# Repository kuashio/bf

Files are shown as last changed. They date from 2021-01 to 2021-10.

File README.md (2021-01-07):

# Brainfuino [-]+.
An Arduino competitor that runs native brainfuck! I've condensed the explanation in this video: https://youtu.be/QloNq8AoHvU

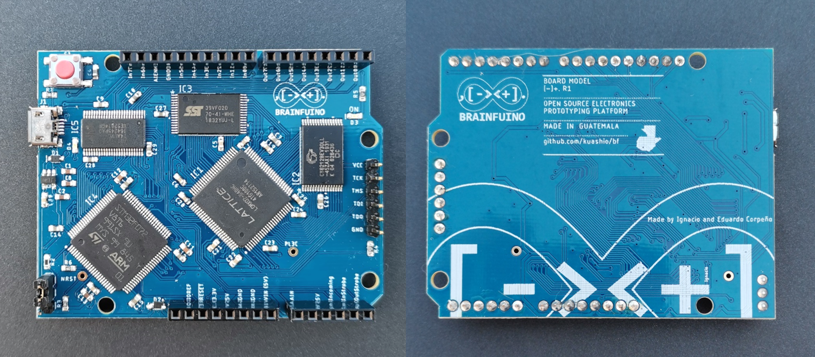
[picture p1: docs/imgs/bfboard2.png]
The Brainfuino [-]+.
[](https://youtu.be/QloNq8AoHvU)

Before going further, please make sure you know (or remember) what brainfuck is. [Here's Wikipedia's entry as a refresher](https://en.wikipedia.org/wiki/Brainfuck).

Also, before moving forward: This is not a joke. It ***is*** about a joke programming language, but a joke lots of nerds are very fond of. When I say nerds, I mean real geeks: Not gamers or technophiles, but geeks who like to read [The Art of Computer Programming](https://en.wikipedia.org/wiki/The_Art_of_Computer_Programming) just for kicks!

The Brainfuino [-]+. (pronounced "Brainfuino Uno") is a development board for a brainfuck soft processor I wrote in Verilog, named [***brainfuck_uP***](https://github.com/kuashio/brainfuck_uP) (as in "brainfuck microprocessor"), which runs brainfuck code natively, that is, the plain text of a brainfuck source file, yes, ascii characters.

Here are some details:

- brainfuck_uP is implemented in a Lattice MachXO2 FPGA, very much like the one in the [TinyFPGA AX2](https://www.sparkfun.com/products/14828) board, but in a TQFP100 package.
- brainfuck_uP is a *Harvard* machine, so it has two separate buses for its program and data memories. 
- The Brainfuino has a 128kB RAM chip and a 256kB chip, both with a good old parallel interface to work as the data and program memories of brainfuck_uP respectively.
- The I/O is adapted from 3.3V logic to TTL with a separate chip (to resemble the Arduino Uno).
- The host computer interface is a USB Virtual COM port implemented with an STM32F072 MCU, which overrides the input/output ports of brainfuck_uP for easy user-brainfuck interaction.
- The MCU is also donating its ADC to give Brainfuino the power of analog input. 
- The board has hardware for updating both the MCU firmware and the FPGA design.

## Advantages over the Arduino Uno

This product is intended as anything around brainfuck and esoteric programming languages: A joke. An elaborate joke. A geek toy.

So, if we take the Arduino as a competitor, here are some advantages:

- Brainfuino runs brainfuck! You'll get to learn a classic esoteric programming language.
- Brainfuino is the only brainfuck MCU platform of its kind (that I know of).
- Brainfuino is capable of at least competing with the Arduino by having an analog input channel.
- Brainfuino may serve as a teaching tool for several things: FPGA soft-processor development, computer science, esoteric programming languages, tinkering, hardware, etc.
- Lots of fun by matching the Arduino Community's codebase.
- Bragging rights for writing code that works! You certainly won't get that from the Arduino. 
- A *Guinness Record* may come out from the Brainfuino Community. Think an Operating System, or an actual home security system!

## Computer Languages

There are three computer languages involved. Only the first one is really intended for the end-user:

- **brainfuck:** Users will write their code in brainfuck, and the Brainfuino will run it.
- **Verilog:** brainfuck_uP was written in Verilog. The final .jedec file may be written into the FPGA's internal ROM at any time.
- **C/C++:** The firmware in the STM32 MCU was written in C. This firmware can be written into the MCU at any time as well.

## Related Projects

- [brainfuck_uP](https://github.com/kuashio/brainfuck_up). The soft processor running on the Brainfuino.
- [Brainfuino MCU firmware](https://github.com/kuashio/brainfuino-firmware). The firmware running in the STM32F072 MCU.

- [Visual brainfuck](https://sites.google.com/site/visualbf/). A brainfuck IDE I finished back in 2011.

## Contact

Eduardo Corpeño

For bug report or anything related to Brainfuino, I may be reached at kuashio@gmail.com

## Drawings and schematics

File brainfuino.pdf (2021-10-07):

J1

# BRD_RST BRD_RST

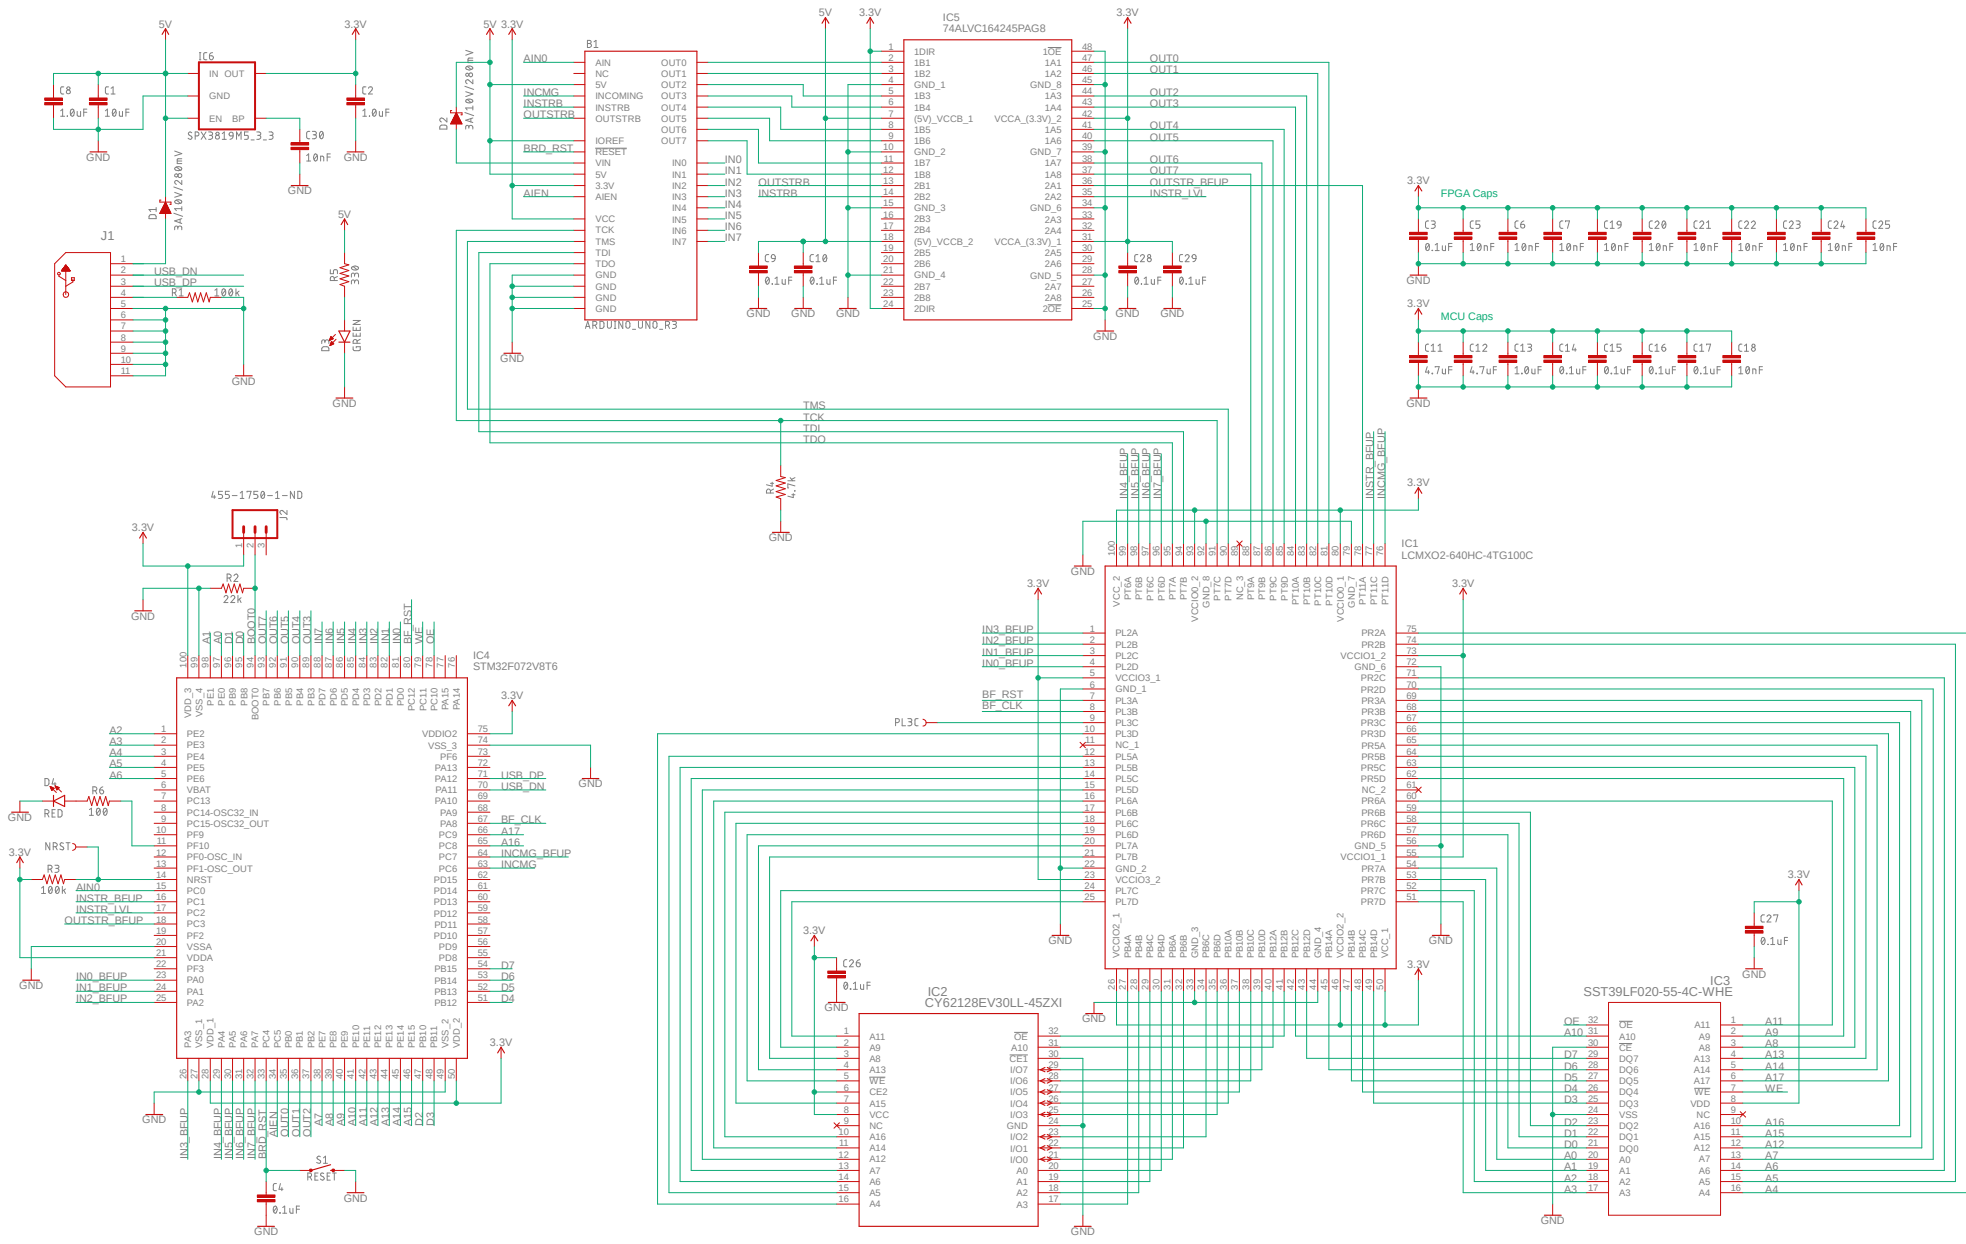
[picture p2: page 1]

TCK
TDI
TDO

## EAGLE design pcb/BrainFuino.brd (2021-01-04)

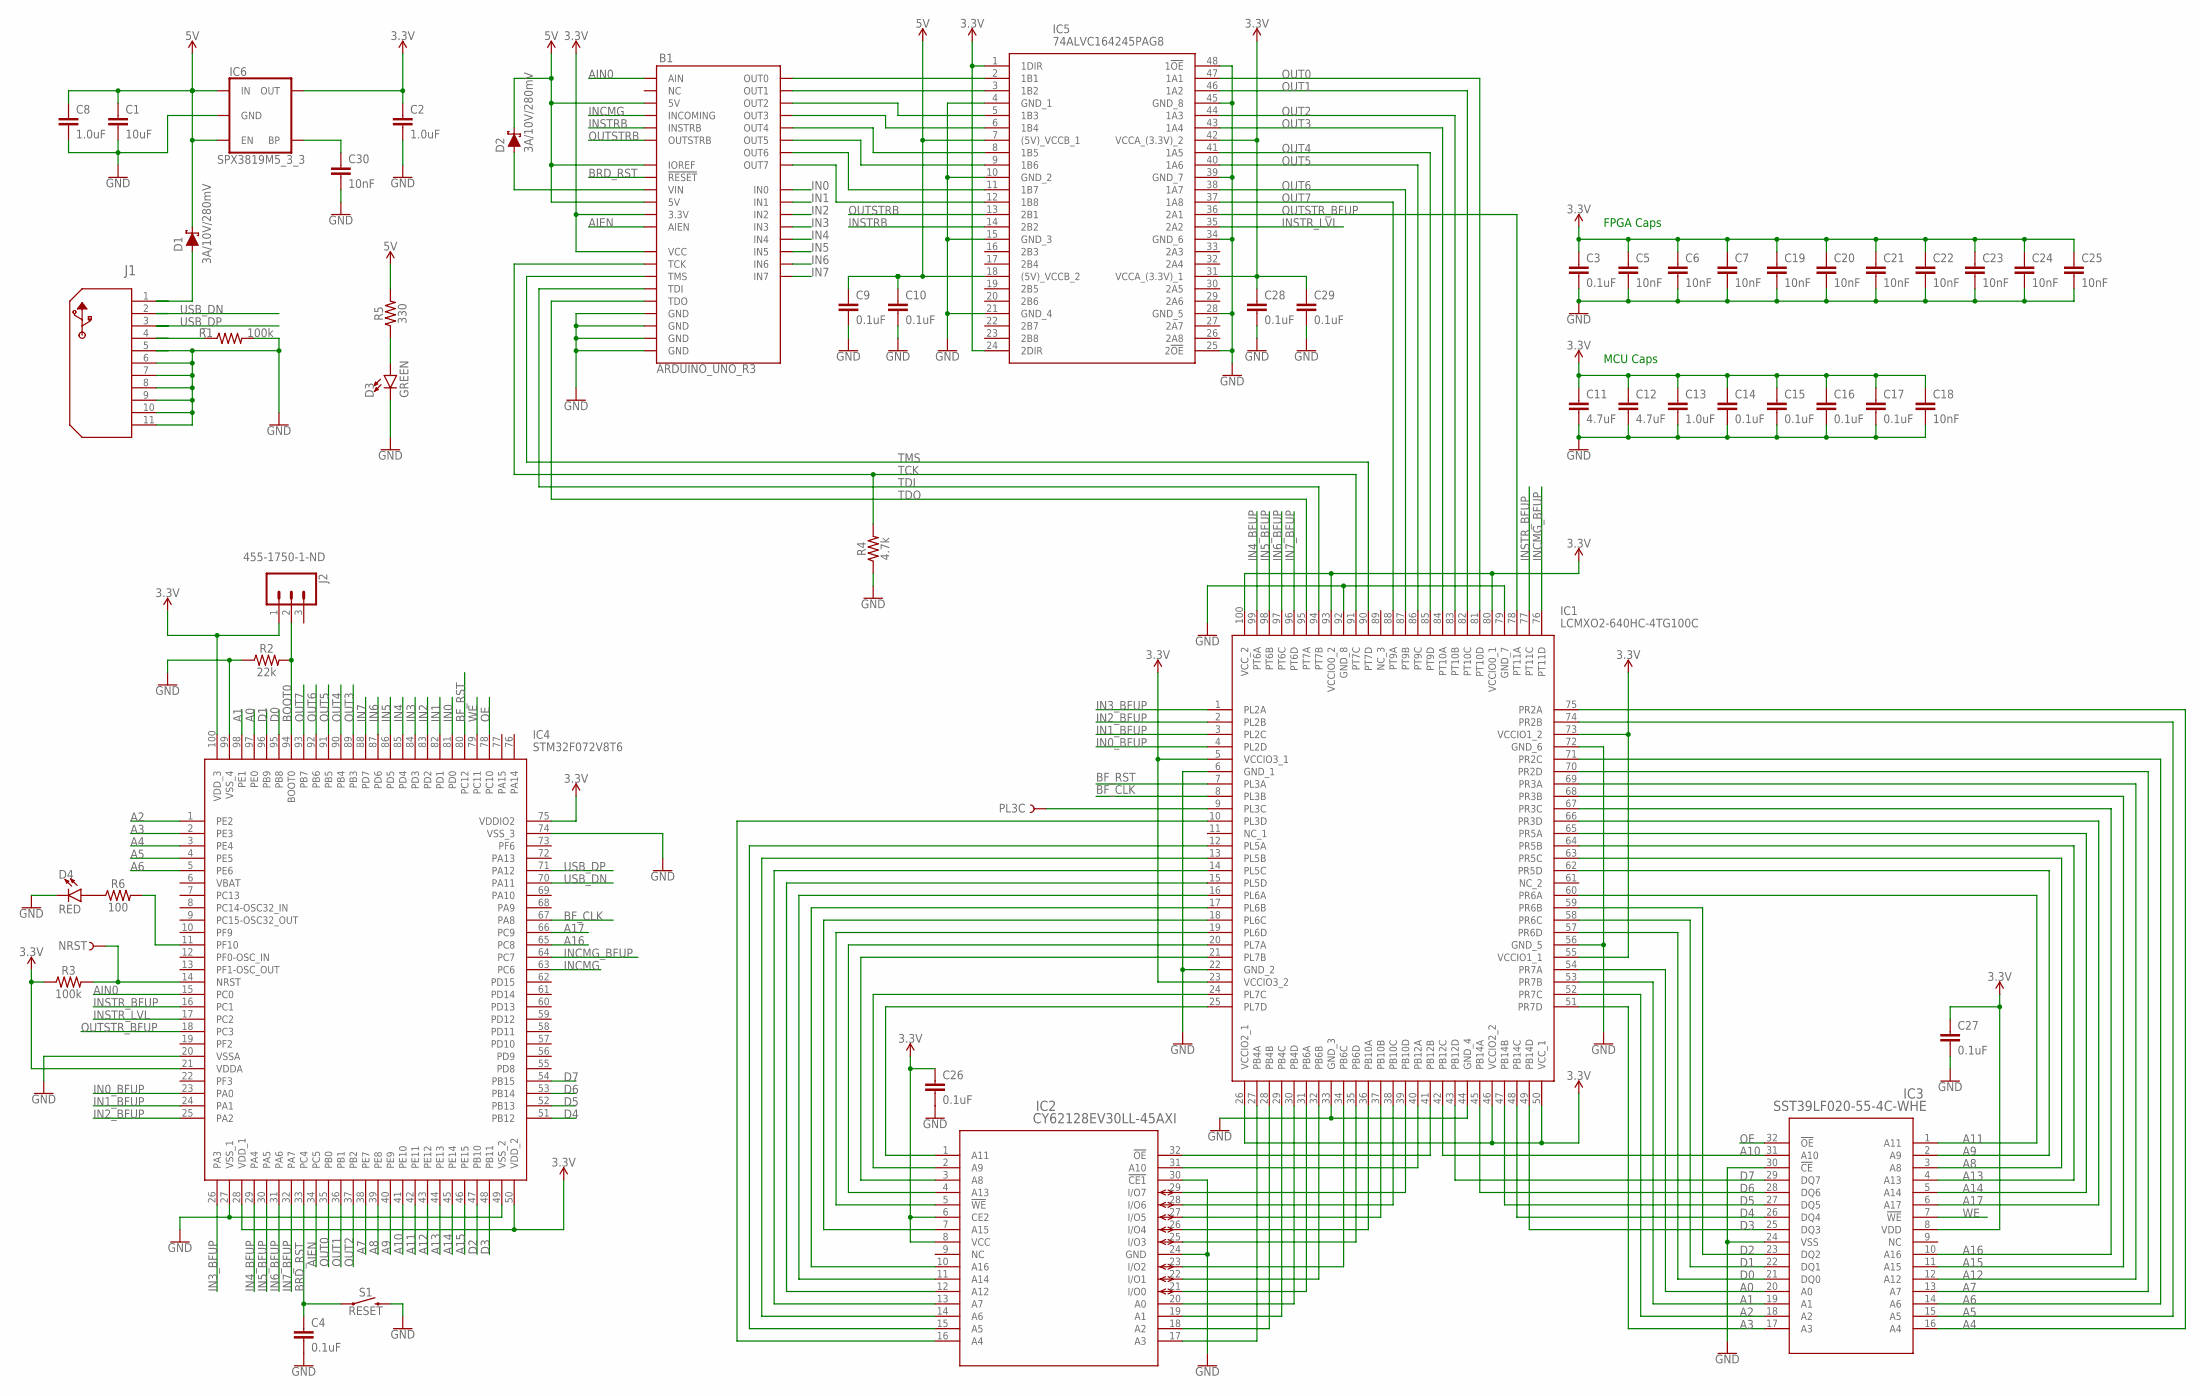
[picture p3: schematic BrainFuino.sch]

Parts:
B1: ARDUINO_UNO_R3; ARDUINO_R3
C1: 10uF; 0603
C2, C8, C13: 1.0uF; 0603
C3, C4, C9, C10, C14, C15, C16, C17, C26, C27, C28, C29: 0.1uF; 0603
C5, C6, C7, C18, C19, C20, C21, C22, C23, C24, C25, C30: 10nF; 0603
C11, C12: 4.7uF; 0603
D1, D2: 3A/10V/280mV; SOD-323
D3: GREEN; LED-0603
D4: RED; LED-0603
IC1: LCMXO2-640HC-4TG100C; QFP50P1600X1600X160-100N
IC2: CY62128EV30LL-45AXI; TSOP-32
IC3: SST39LF020-55-4C-WHE; TSOP32_WH_SST
IC4: STM32F072V8T6; QFP50P1600X1600X160-100N
IC5: 74ALVC164245PAG8; SOP50P810X120-48N
IC6: SPX3819M5_3_3; SOT23-5
J1: 1981568-1; CONN5_1981568-1_TEC
J2: 455-1750-1-ND; 1X03
NRST: TEST-POINTPOGO_PTH; 1X01_NO_SILK
PL3C: TEST-POINTPOGO_PTH; 1X01_NO_SILK
R1, R3: 100k; 0603
R2: 22k; 0603
R4: 4.7k; 0603
R5: 330; 0603
R6: 100; 0603
S1: RESET; TACTILE_SWITCH_SMD_6.2MM_TALL

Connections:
3.3V: B1.3.3V, B1.VCC, C2.1, C3.1, C5.1, C6.1, C7.1, C11.1, C12.1, C13.1, C14.1, C15.1, C16.1, C17.1, C18.1, C19.1, C20.1, C21.1, C22.1, C23.1, C24.1, C25.1, C26.1, C27.1, C28.1, C29.1, IC1.5 (VCCIO3_1), IC1.23 (VCCIO3_2), IC1.26 (VCCIO2_1), IC1.46 (VCCIO2_2), IC1.50 (VCC_1), IC1.55 (VCCIO1_1), IC1.73 (VCCIO1_2), IC1.80 (VCCIO0_1), IC1.93 (VCCIO0_2), IC1.100 (VCC_2), IC2.6 (CE2), IC2.8 (VCC), IC3.8 (VDD), IC4.21 (VDDA), IC4.28 (VDD_1), IC4.50 (VDD_2), IC4.75 (VDDIO2), IC4.100 (VDD_3), IC5.1 (1DIR), IC5.24 (2DIR), IC5.31 (VCCA_(3.3V)_1), IC5.42 (VCCA_(3.3V)_2), IC6.5 (OUT), J2.1, R3.1
5V: B1.5V, B1.5V@1 (5V), B1.IOREF, C1.1, C8.1, C9.1, C10.1, D1.C, D2.C, IC5.7 ((5V)_VCCB_1), IC5.18 ((5V)_VCCB_2), IC6.1 (IN), IC6.3 (EN), R5.2
A0: IC1.54 (PR7A), IC3.20 (A0), IC4.97 (PE0)
A1: IC1.53 (PR7B), IC3.19 (A1), IC4.98 (PE1)
A2: IC1.52 (PR7C), IC3.18 (A2), IC4.1 (PE2)
A3: IC1.51 (PR7D), IC3.17 (A3), IC4.2 (PE3)
A4: IC1.75 (PR2A), IC3.16 (A4), IC4.3 (PE4)
A5: IC1.74 (PR2B), IC3.15 (A5), IC4.4 (PE5)
A6: IC1.71 (PR2C), IC3.14 (A6), IC4.5 (PE6)
A7: IC1.70 (PR2D), IC3.13 (A7), IC4.38 (PE7)
A8: IC1.63 (PR5C), IC3.3 (A8), IC4.39 (PE8)
A9: IC1.62 (PR5D), IC3.2 (A9), IC4.40 (PE9)
A10: IC1.42 (PB12C), IC3.31 (A10), IC4.41 (PE10)
A11: IC1.60 (PR6A), IC3.1 (A11), IC4.42 (PE11)
A12: IC1.69 (PR3A), IC3.12 (A12), IC4.43 (PE12)
A13: IC1.64 (PR5B), IC3.4 (A13), IC4.44 (PE13)
A14: IC1.65 (PR5A), IC3.5 (A14), IC4.45 (PE14)
A15: IC1.68 (PR3B), IC3.11 (A15), IC4.46 (PE15)
A16: IC1.67 (PR3C), IC3.10 (A16), IC4.65 (PC8)
A17: IC1.66 (PR3D), IC3.6 (A17), IC4.66 (PC9)
AIEN: B1.AREF (AIEN), IC4.34 (PC5)
AIN0: B1.AIN, IC4.15 (PC0)
BF_CLK: IC1.8 (PL3B), IC4.67 (PA8)
BF_RST: IC1.7 (PL3A), IC4.80 (PC12)
BOOT0: IC4.94 (BOOT0), J2.2, R2.2
BRD_RST: B1.RESET@1 (!RESET!), C4.1, IC4.33 (PC4), S1.A2 (1)
D0: IC1.57 (PR6D), IC3.21 (DQ0), IC4.95 (PB8)
D1: IC1.58 (PR6C), IC3.22 (DQ1), IC4.96 (PB9)
D2: IC1.59 (PR6B), IC3.23 (DQ2), IC4.47 (PB10)
D3: IC1.49 (PB14D), IC3.25 (DQ3), IC4.48 (PB11)
D4: IC1.48 (PB14C), IC3.26 (DQ4), IC4.51 (PB12)
D5: IC1.47 (PB14B), IC3.27 (DQ5), IC4.52 (PB13)
D6: IC1.45 (PB14A), IC3.28 (DQ6), IC4.53 (PB14)
D7: IC1.43 (PB12D), IC3.29 (DQ7), IC4.54 (PB15)
GND: B1.GND@1 (GND), B1.GND@2 (GND), B1.GND@3 (GND), B1.GND@4 (GND), C1.2, C2.2, C3.2, C4.2, C5.2, C6.2, C7.2, C8.2, C9.2, C10.2, C11.2, C12.2, C13.2, C14.2, C15.2, C16.2, C17.2, C18.2, C19.2, C20.2, C21.2, C22.2, C23.2, C24.2, C25.2, C26.2, C27.2, C28.2, C29.2, C30.2, D3.C, D4.C, IC1.6 (GND_1), IC1.22 (GND_2), IC1.33 (GND_3), IC1.44 (GND_4), IC1.56 (GND_5), IC1.72 (GND_6), IC1.79 (GND_7), IC1.92 (GND_8), IC2.24 (GND), IC2.30 (!CE1), IC3.24 (VSS), IC3.30 (!CE), IC4.20 (VSSA), IC4.27 (VSS_1), IC4.49 (VSS_2), IC4.74 (VSS_3), IC4.99 (VSS_4), IC5.4 (GND_1), IC5.10 (GND_2), IC5.15 (GND_3), IC5.21 (GND_4), IC5.25 (2!OE), IC5.28 (GND_5), IC5.34 (GND_6), IC5.39 (GND_7), IC5.45 (GND_8), IC5.48 (1!OE), IC6.2 (GND), J1.5, J1.6, J1.7, J1.8, J1.9, J1.10, J1.11, R1.2, R2.1, R4.1, S1.B2 (2)
IN0: B1.IN0, IC4.81 (PD0)
IN0_BFUP: IC1.4 (PL2D), IC4.23 (PA0)
IN1: B1.IN1, IC4.82 (PD1)
IN1_BFUP: IC1.3 (PL2C), IC4.24 (PA1)
IN2: B1.IN2, IC4.83 (PD2)
IN2_BFUP: IC1.2 (PL2B), IC4.25 (PA2)
IN3: B1.IN3, IC4.84 (PD3)
IN3_BFUP: IC1.1 (PL2A), IC4.26 (PA3)
IN4: B1.IN4, IC4.85 (PD4)
IN4_BFUP: IC1.99 (PT6A), IC4.29 (PA4)
IN5: B1.IN5, IC4.86 (PD5)
IN5_BFUP: IC1.98 (PT6B), IC4.30 (PA5)
IN6: B1.IN6, IC4.87 (PD6)
IN6_BFUP: IC1.97 (PT6C), IC4.31 (PA6)
IN7: B1.IN7, IC4.88 (PD7)
IN7_BFUP: IC1.96 (PT6D), IC4.32 (PA7)
INCMG: B1.INCOMING, IC4.63 (PC6)
INCMG_BFUP: IC1.76 (PT11D), IC4.64 (PC7)
INSTRB: B1.INST (INSTRB), IC5.14 (2B2)
INSTR_BFUP: IC1.77 (PT11C), IC4.16 (PC1)
INSTR_LVL: IC4.17 (PC2), IC5.35 (2A2)
unnamed: IC1.28 (PB4B), IC2.18 (A2)
unnamed: IC1.29 (PB4C), IC2.19 (A1)
unnamed: IC1.30 (PB4D), IC2.20 (A0)
unnamed: IC1.31 (PB6A), IC2.21 (I/O0)
unnamed: IC1.32 (PB6B), IC2.22 (I/O1)
unnamed: IC1.34 (PB6C), IC2.23 (I/O2)
unnamed: IC1.35 (PB6D), IC2.25 (I/O3)
unnamed: IC1.41 (PB12B), IC2.32 (!OE)
unnamed: IC1.27 (PB4A), IC2.17 (A3)
unnamed: IC1.36 (PB10A), IC2.26 (I/O4)
unnamed: IC1.37 (PB10B), IC2.27 (I/O5)
unnamed: IC1.38 (PB10C), IC2.28 (I/O6)
unnamed: IC1.39 (PB10D), IC2.29 (I/O7)
unnamed: IC1.40 (PB12A), IC2.31 (A10)
unnamed: IC1.9 (PL3C), PL3C.1
unnamed: D3.A, R5.1
unnamed: C30.1, IC6.4 (BP)
unnamed: B1.VIN, D2.A
unnamed: D1.A, J1.1
unnamed: IC4.11 (PF10), R6.2
unnamed: D4.A, R6.1
unnamed: IC4.14 (NRST), NRST.1, R3.2
unnamed: B1.OUT0, IC5.2 (1B1)
unnamed: IC1.25 (PL7D), IC2.1 (A11)
unnamed: IC1.24 (PL7C), IC2.2 (A9)
unnamed: IC1.21 (PL7B), IC2.3 (A8)
unnamed: IC1.18 (PL6C), IC2.7 (A15)
unnamed: IC1.15 (PL5D), IC2.12 (A12)
unnamed: IC1.14 (PL5C), IC2.13 (A7)
unnamed: IC1.13 (PL5B), IC2.14 (A6)
unnamed: IC1.12 (PL5A), IC2.15 (A5)
unnamed: IC1.10 (PL3D), IC2.16 (A4)
unnamed: B1.OUT1, IC5.3 (1B2)
unnamed: B1.OUT2, IC5.5 (1B3)
unnamed: B1.OUT3, IC5.6 (1B4)
unnamed: B1.OUT4, IC5.8 (1B5)
unnamed: B1.OUT5, IC5.9 (1B6)
unnamed: IC1.17 (PL6B), IC2.10 (A16)
unnamed: B1.OUT6, IC5.11 (1B7)
unnamed: B1.OUT7, IC5.12 (1B8)
unnamed: IC1.20 (PL7A), IC2.4 (A13)
unnamed: IC1.19 (PL6D), IC2.5 (!WE)
unnamed: IC1.16 (PL6A), IC2.11 (A14)
unnamed: J1.4, R1.1
OE: IC3.32 (!OE), IC4.78 (PC10)
OUT0: IC1.81 (PT10D), IC4.35 (PB0), IC5.47 (1A1)
OUT1: IC1.82 (PT10C), IC4.36 (PB1), IC5.46 (1A2)
OUT2: IC1.83 (PT10B), IC4.37 (PB2), IC5.44 (1A3)
OUT3: IC1.84 (PT10A), IC4.89 (PB3), IC5.43 (1A4)
OUT4: IC1.85 (PT9D), IC4.90 (PB4), IC5.41 (1A5)
OUT5: IC1.86 (PT9C), IC4.91 (PB5), IC5.40 (1A6)
OUT6: IC1.87 (PT9B), IC4.92 (PB6), IC5.38 (1A7)
OUT7: IC1.88 (PT9A), IC4.93 (PB7), IC5.37 (1A8)
OUTSTRB: B1.OUTST (OUTSTRB), IC5.13 (2B1)
OUTSTR_BFUP: IC1.78 (PT11A), IC4.18 (PC3), IC5.36 (2A1)
TCK: B1.TCK, IC1.91 (PT7C), R4.2
TDI: B1.TDI, IC1.94 (PT7B)
TDO: B1.TDO, IC1.95 (PT7A)
TMS: B1.TMS, IC1.90 (PT7D)
USB_DN: IC4.70 (PA11), J1.2
USB_DP: IC4.71 (PA12), J1.3
WE: IC3.7 (!WE), IC4.79 (PC11)

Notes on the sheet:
FPGA Caps
MCU Caps

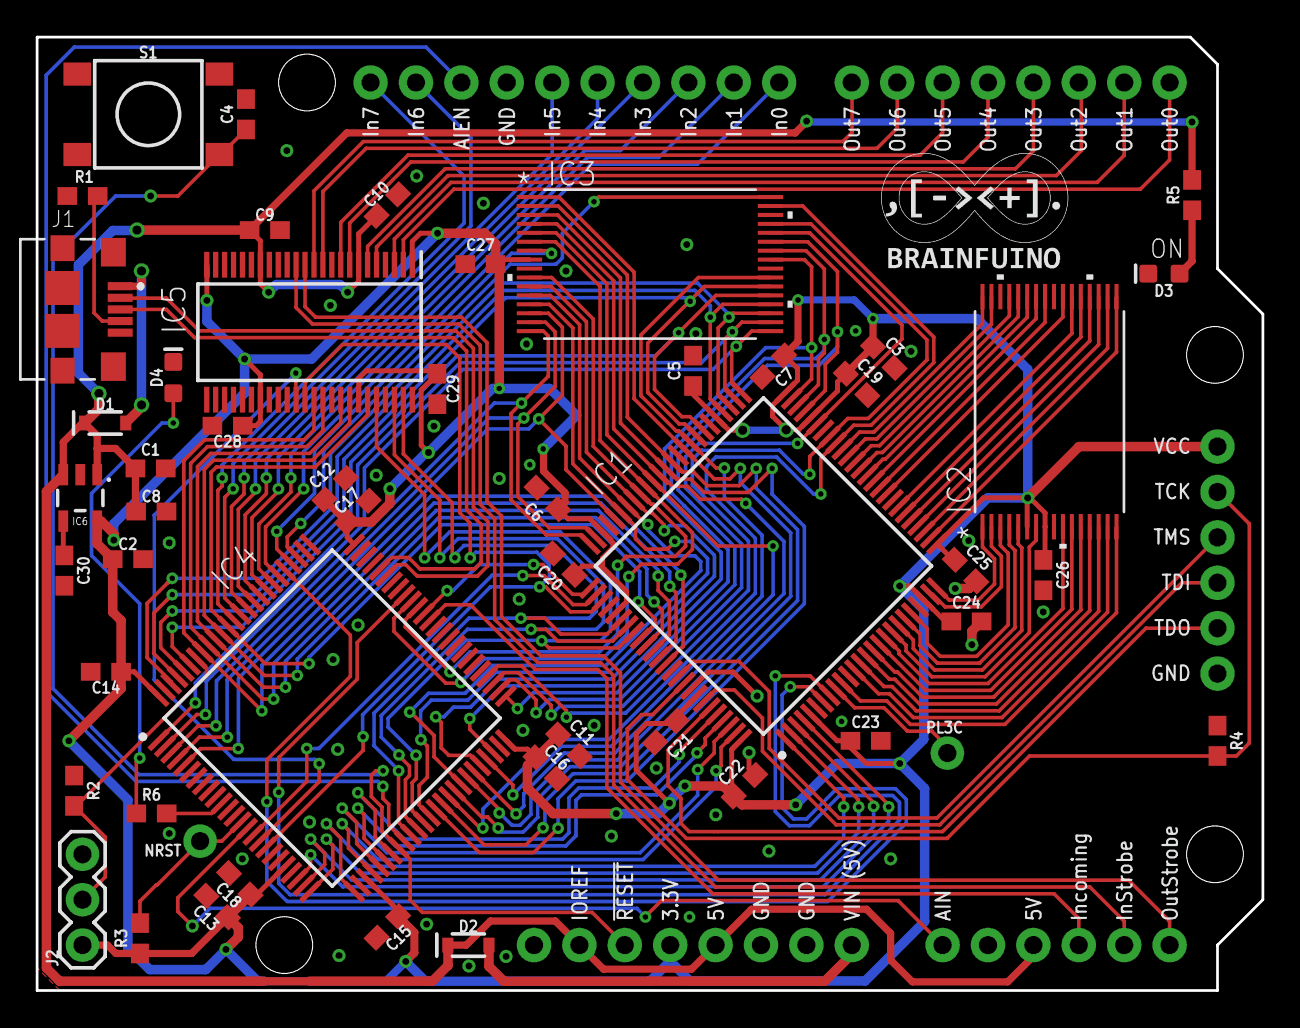
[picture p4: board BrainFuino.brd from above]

Board: 2 copper layers, 68.6 x 53.3 mm, 52 parts (0 on the bottom side), 118 nets.

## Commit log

2021-01-04 added pcb folder
    [BrainFuino.brd, BrainFuino.sch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]
2021-10-07 added schematic pdf

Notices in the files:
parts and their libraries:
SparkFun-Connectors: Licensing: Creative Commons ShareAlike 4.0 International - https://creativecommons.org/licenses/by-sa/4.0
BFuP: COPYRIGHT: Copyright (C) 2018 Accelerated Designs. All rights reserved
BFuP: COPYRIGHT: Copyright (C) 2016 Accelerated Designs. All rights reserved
